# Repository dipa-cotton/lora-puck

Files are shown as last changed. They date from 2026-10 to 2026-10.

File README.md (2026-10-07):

# lora-puck
LoRA!!
## pictures
Screenshot 2026-10-07 at 12 41 12 AM
Screenshot 2026-10-07 at 12 42 32 AM
Screenshot 2026-10-07 at 12 42 04 AM
Screenshot 2026-10-07 at 12 41 37 AM

## project overview
A long range radio system with lots of features! it integrates boards with sensors and reads the data with an esp32, and communicates using an SX1262, on ham radio frequencies so i can pick them up from far far away :DD along with a 0.96 inch OLED display, a microSD card module, and more, this project is versatile and can do much more than your average tiny radio!
## pictures
There was no CAD Case built because this is going to be put in a solar powered plane built by an organization that I don't have the dimentions for yet. I will update the CAD as soon as I receive those dimentions!
### Overall Cost: $72
see BOM.csv for more specifics!

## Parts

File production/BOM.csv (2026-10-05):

Reference | Qty | Value | Cost | Link | Footprint | Datasheet
BT1 | 1 | Battery | 0.5 | https://www.aliexpress.us/item/3256807960114360.html?curPageLogUid=OKZYJvWZM2wn | Battery:BatteryHolder_Keystone_2462_2xAA
SW1,SW2 | 2 | SW_Push | Owned |  | Button_Switch_SMD:SW_Push_1P1T_NO_CK_PTS125Sx43SMTR
C1,C3,C4 | 3 | 100nf | 4 | https://www.aliexpress.com/ssr/300000512/BundleDeals2?productIds=1005006186888242%3A12000036220573161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 | Capacitor_SMD:C_0402_1005Metric_Pad0.74x0.62mm_HandSolder
C5 | 1 | 4.7 µF | included in kit |  | Capacitor_SMD:C_0402_1005Metric_Pad0.74x0.62mm_HandSolder
C6,C7 | 2 | 10 µF | included in kit |  | Capacitor_SMD:C_0402_1005Metric_Pad0.74x0.62mm_HandSolder
C12 | 1 | C_Polarized | Owned |  | Capacitor_THT:C_Radial_D6.3mm_H7.0mm_P2.50mm
J7 | 1 | Micro_SD_Card | 3.5 | https://www.mouser.com/en/ProductDetail/Wurth-Elektronik/693072010801?qs=7gQLVZk5cPmw4uU1mAcUFg%3D%3D | Connector_Card:microSD_HC_Wuerth_693072010801 | https://www.we-online.com/components/products/datasheet/693072010801.pdf
J3 | 1 | UV Sensor 240-370nm GUVA-S12SD 3528 | 3 | https://www.aliexpress.us/item/3256806094286151.html | Connector_PinHeader_2.54mm:PinHeader_1x03_P2.54mm_Vertical
J4 | 1 | AHT20+BMP280 Temperature Humidity Air Pressure | 3 | https://www.aliexpress.us/item/3256807516159141.html | Connector_PinHeader_2.54mm:PinHeader_1x04_P2.54mm_Vertical
J6 | 1 | GY-NEO6MV2 New NEO-6M GPS | 3 | https://www.aliexpress.us/item/3256807316352883.html | Connector_PinHeader_2.54mm:PinHeader_1x04_P2.54mm_Vertical
J8 | 1 | OLED | 3 | https://www.aliexpress.us/item/3256812792834091.html | Connector_PinHeader_2.54mm:PinHeader_1x04_P2.54mm_Vertical
J5 | 1 | 7700 Ambient Light Sensor | 3 | https://www.aliexpress.us/item/3256810505327028.html | Connector_PinHeader_2.54mm:PinHeader_1x05_P2.54mm_Vertical
J2 | 1 | ENS160+AHT21 | 3 | https://www.aliexpress.us/item/3256808312530292.html | Connector_PinHeader_2.54mm:PinHeader_1x08_P2.54mm_Vertical
J1 | 1 | USB_C_Receptacle_USB2.0_14P | 1 | https://www.digikey.com/en/products/detail/gct/USB4085-GF-A/9859662 | Connector_USB:USB_C_Receptacle_GCT_USB4085 | https://www.usb.org/sites/default/files/documents/usb_type-c.zip
Y1 | 1 | Crystal_GND24 | 0.5 | https://www.mouser.com/en/ProductDetail/Murata-Electronics/CSTLS16M0X55-B0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 | Crystal:Crystal_DS10_D1.0mm_L4.3mm_Horizontal_1EP_style1
FB1 | 1 | FerriteBead | 1.1 | https://www.digikey.com/en/products/detail/laird-signal-integrity-products/28C0236-0JW-10/806596 | Ferrite_THT:LairdTech_28C0236-0JW-10
U2 | 1 | SX1262IMLTRT | 9 | https://www.digikey.com/en/products/detail/semtech-corporation/SX1262IMLTRT/8564369 | Package_DFN_QFN:QFN-24-1EP_4x4mm_P0.5mm_EP2.6x2.6mm | https://semtech.file.force.com/sfc/dist/version/download/?oid=00DE0000000JelG&ids=0682R00000IjPWSQA3
U3 | 1 | AMS1117-3.3 | 0.5 | https://www.digikey.com/en/products/detail/umw/AMS1117-3-3/17635254 | Package_TO_SOT_SMD:SOT-223-3_TabPin2 | http://www.advanced-monolithic.com/pdf/ds1117.pdf
U4 | 1 | PE4259 | 1 | https://www.digikey.com/en/products/detail/psemi/4259-63/2614473 | Package_TO_SOT_SMD:SOT-363_SC-70-6 | https://lcsc.com/datasheet/lcsc_datasheet_2409301504_pSemi-PE4259-63_C470892.pdf
U5 | 1 | MCP1700x-330xxTO | 0.5 | https://www.digikey.com/en/products/detail/microchip-technology/MCP1700-3302E-TO/652680 | Package_TO_SOT_THT:TO-92_Inline | http://ww1.microchip.com/downloads/en/DeviceDoc/20001826D.pdf
L1 | 1 | 15µH | 1 | https://www.digikey.com/en/products/detail/bourns-inc/RL622-150K-RC/946867 | Resistor_SMD:R_0402_1005Metric_Pad0.72x0.64mm_HandSolder
L2 | 1 | 9.1nH | 0.5 | https://www.digikey.com/en/products/detail/murata-electronics/LQG15WZ9N1G02D/18679099?gclsrc=aw.ds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 | Resistor_SMD:R_0402_1005Metric_Pad0.72x0.64mm_HandSolder
R1,R2 | 2 | 5.1K | 4 | https://www.aliexpress.com/ssr/300000512/BundleDeals2?productIds=1005010764873718%3A12000053431302920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 | Resistor_SMD:R_0402_1005Metric_Pad0.72x0.64mm_HandSolder
R3,R4 | 2 | 10k | included in kit |  | Resistor_SMD:R_0402_1005Metric_Pad0.72x0.64mm_HandSolder
C2 | 1 | 1µF | included in kit |  | Resistor_SMD:R_0603_1608Metric
C8 | 1 | C | included in kit |  | Resistor_SMD:R_0603_1608Metric
C9 | 1 | 39pf | included in kit |  | Resistor_SMD:R_0603_1608Metric
C10,C11 | 2 | 3.3 pf | included in kit |  | Resistor_SMD:R_0603_1608Metric
C13 | 1 | 10µF | included in kit |  | Resistor_SMD:R_0603_1608Metric
C14 | 1 | 0.1µF | included in kit |  | Resistor_SMD:R_0603_1608Metric
R5 | 1 | 10D | included in kit |  | Resistor_SMD:R_0603_1608Metric
FL2 | 1 | 0900FM15K0039 | 0.5 | https://www.digikey.com/en/products/detail/johanson-technology-inc/0900FM15K0039001E/16639329 | RF_Converter:Balun_Johanson_0900FM15K0039 | https://www.johansontechnology.com/datasheets/0900FM15K0039/0900FM15K0039.pdf
U1 | 1 | ESP32-S3-WROOM-1 | 7 | https://www.digikey.com/en/products/detail/espressif-systems/ESP32-S3-WROOM-1-N8R8/15295891 | RF_Module:ESP32-S3-WROOM-1 | https://www.espressif.com/sites/default/files/documentation/esp32-s3-wroom-1_wroom-1u_datasheet_en.pdf
 |  |  | 52.1
 |  | shipping | 10 | 5 | 7
 |  | total | 74.1

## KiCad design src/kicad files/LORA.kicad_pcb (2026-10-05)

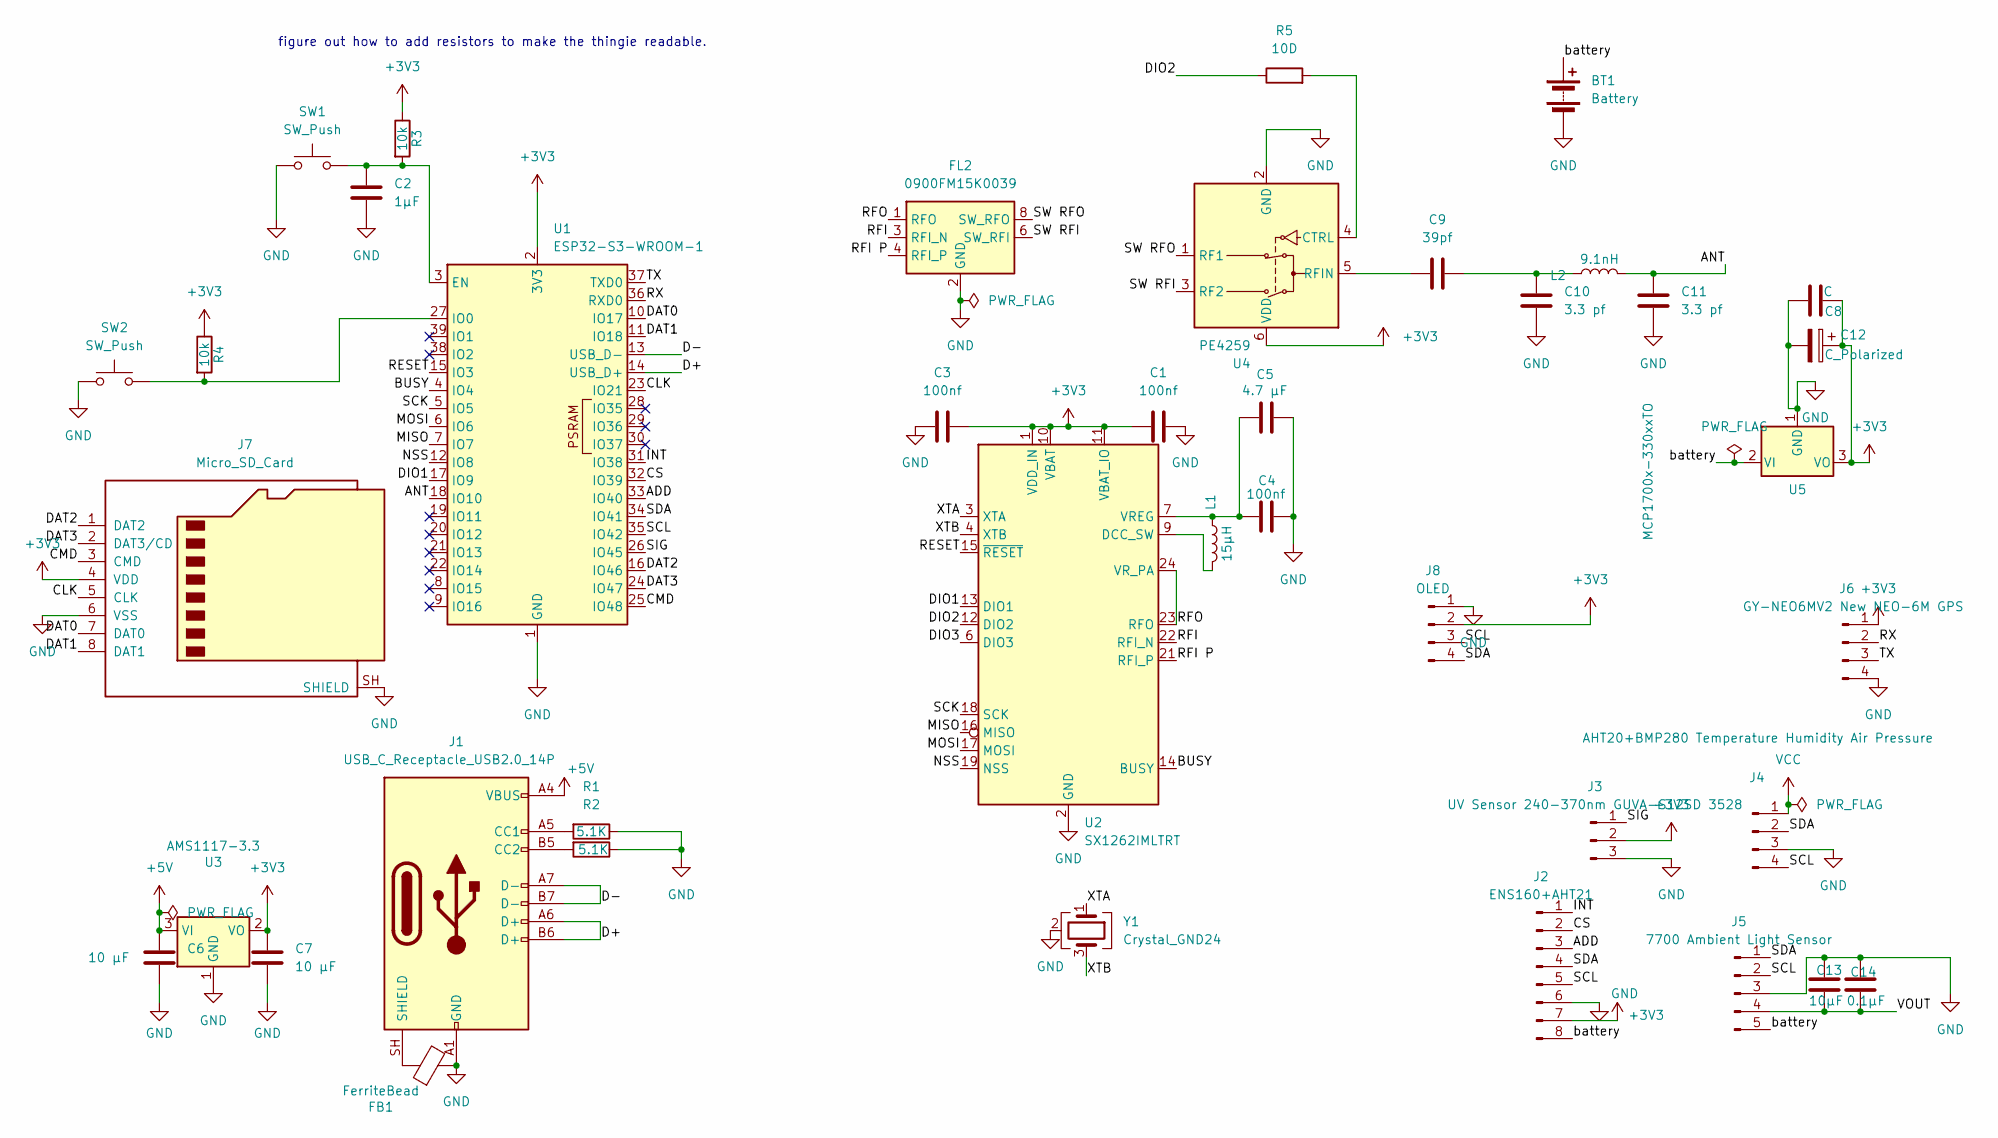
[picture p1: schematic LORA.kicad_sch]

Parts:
BT1: Battery; BatteryHolder_Keystone_2462_2xAA
C1, C3, C4: 100nf; C_0402_1005Metric_Pad0.74x0.62mm_HandSolder
C2: 1µF; R_0603_1608Metric
C5: 4.7 µF; C_0402_1005Metric_Pad0.74x0.62mm_HandSolder
C6, C7: 10 µF; C_0402_1005Metric_Pad0.74x0.62mm_HandSolder
C8: C; R_0603_1608Metric
C9: 39pf; R_0603_1608Metric
C10, C11: 3.3 pf; R_0603_1608Metric
C12: C_Polarized; C_Radial_D6.3mm_H7.0mm_P2.50mm
C13: 10µF; R_0603_1608Metric
C14: 0.1µF; R_0603_1608Metric
FB1: FerriteBead; LairdTech_28C0236-0JW-10
FL2: 0900FM15K0039; Balun_Johanson_0900FM15K0039
J1: USB_C_Receptacle_USB2.0_14P; USB_C_Receptacle_GCT_USB4085
J2: ENS160+AHT21; PinHeader_1x08_P2.54mm_Vertical
J3: UV Sensor 240-370nm GUVA-S12SD 3528; PinHeader_1x03_P2.54mm_Vertical
J4: AHT20+BMP280 Temperature Humidity Air Pressure; PinHeader_1x04_P2.54mm_Vertical
J5: 7700 Ambient Light Sensor; PinHeader_1x05_P2.54mm_Vertical
J6: GY-NEO6MV2 New NEO-6M GPS; PinHeader_1x04_P2.54mm_Vertical
J7: Micro_SD_Card; microSD_HC_Wuerth_693072010801
J8: OLED; PinHeader_1x04_P2.54mm_Vertical
L1: 15µH; R_0402_1005Metric_Pad0.72x0.64mm_HandSolder
L2: 9.1nH; R_0402_1005Metric_Pad0.72x0.64mm_HandSolder
R1, R2: 5.1K; R_0402_1005Metric_Pad0.72x0.64mm_HandSolder
R3, R4: 10k; R_0402_1005Metric_Pad0.72x0.64mm_HandSolder
R5: 10D; R_0603_1608Metric
SW1, SW2: SW_Push; SW_Push_1P1T_NO_CK_PTS125Sx43SMTR
U1: ESP32-S3-WROOM-1
U2: SX1262IMLTRT; QFN-24-1EP_4x4mm_P0.5mm_EP2.6x2.6mm
U3: AMS1117-3.3; SOT-223-3_TabPin2
U4: PE4259; SOT-363_SC-70-6
U5: MCP1700x-330xxTO; TO-92_Inline
Y1: Crystal_GND24; Crystal_DS10_D1.0mm_L4.3mm_Horizontal_1EP_style1

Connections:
+3V3: C1.1, C3.2, C7.1, C8.1, C12.1, J2.7, J3.2, J6.1, J7.4 (VDD), J8.2, R3.1, R4.1, U1.2 (3V3), U2.1 (VDD_IN), U2.10 (VBAT), U2.11 (VBAT_IO), U3.2 (VO), U4.6 (VDD), U5.3 (VO)
+5V: C6.1, J1.A4 (VBUS), J1.A9 (VBUS), J1.B4 (VBUS), J1.B9 (VBUS), U3.3 (VI)
/ADD: J2.3, U1.33 (IO40)
/ANT: C11.2, L2.2, U1.18 (IO10)
/BUSY: U1.4 (IO4), U2.14 (BUSY)
/CLK: J7.5 (CLK), U1.23 (IO21)
/CMD: J7.3 (CMD), U1.25 (IO48)
/CS: J2.2, U1.32 (IO39)
/D+: J1.A6 (D+), J1.B6 (D+), U1.14 (USB_D+)
/D-: J1.A7 (D-), J1.B7 (D-), U1.13 (USB_D-)
/DAT0: J7.7 (DAT0), U1.10 (IO17)
/DAT1: J7.8 (DAT1), U1.11 (IO18)
/DAT2: J7.1 (DAT2), U1.16 (IO46)
/DAT3: J7.2 (DAT3/CD), U1.24 (IO47)
/DIO1: U1.17 (IO9), U2.13 (DIO1)
/DIO2: R5.1, U2.12 (DIO2)
/DIO3: U2.6 (DIO3)
/INT: J2.1, U1.31 (IO38)
/MISO: U1.7 (IO7), U2.16 (MISO)
/MOSI: U1.6 (IO6), U2.17 (MOSI)
/NSS: U1.12 (IO8), U2.19 (NSS)
/RESET: U1.15 (IO3), U2.15 (~RESET)
/RFI: FL2.3 (RFI_N), U2.22 (RFI_N)
/RFI P: FL2.4 (RFI_P), U2.21 (RFI_P)
/RFO: FL2.1 (RFO), U2.23 (RFO), U2.24 (VR_PA)
/RX: J6.2, U1.36 (RXD0)
/SCK: U1.5 (IO5), U2.18 (SCK)
/SCL: J2.5, J4.4, J5.2, J8.3, U1.35 (IO42)
/SDA: J2.4, J4.2, J5.1, J8.4, U1.34 (IO41)
/SIG: J3.1, U1.26 (IO45)
/SW RFI: FL2.6 (SW_RFI), U4.3 (RF2)
/SW RFO: FL2.8 (SW_RFO), U4.1 (RF1)
/TX: J6.3, U1.37 (TXD0)
/VOUT: C13.2, C14.2, J5.4
/XTA: U2.3 (XTA), Y1.1
/XTB: U2.4 (XTB), Y1.3
/battery: BT1.1 (+), J2.8, J5.5, U5.2 (VI)
GND: BT1.2 (-), C1.2, C2.2, C3.1, C4.2, C5.2, C6.2, C7.2, C8.2, C10.1, C11.1, C12.2, C13.1, C14.1, FB1.2, FL2.2 (GND), FL2.5 (GND), FL2.7 (GND), FL2.9 (GND), FL2.10 (GND), J1.A1 (GND), J1.A12 (GND), J1.B1 (GND), J1.B12 (GND), J2.6, J3.3, J4.3, J5.3, J6.4, J7.6 (VSS), J7.SH (SHIELD), J8.1, R1.1, R2.1, SW1.1, SW2.1, U1.1 (GND), U1.40 (GND), U1.41 (GND), U2.2 (GND), U2.5 (GND), U2.8 (GND), U2.20 (GND), U2.25 (GND), U3.1 (GND), U4.2 (GND), U5.1 (GND), Y1.2 (G), Y1.4 (G)
unnamed: C9.1, C10.2, L2.1
unnamed: J1.A5 (CC1), R1.2
unnamed: J1.B5 (CC2), R2.2
unnamed: FB1.1, J1.SH (SHIELD)
unnamed: C2.1, R3.2, SW1.2, U1.3 (EN)
unnamed: R4.2, SW2.2, U1.27 (IO0)
unnamed: L1.2, U2.9 (DCC_SW)
unnamed: C4.1, C5.1, L1.1, U2.7 (VREG)
unnamed: R5.2, U4.4 (CTRL)
unnamed: C9.2, U4.5 (RFIN)
VCC: J4.1

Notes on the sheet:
figure out how to add resistors to make the thingie readable.

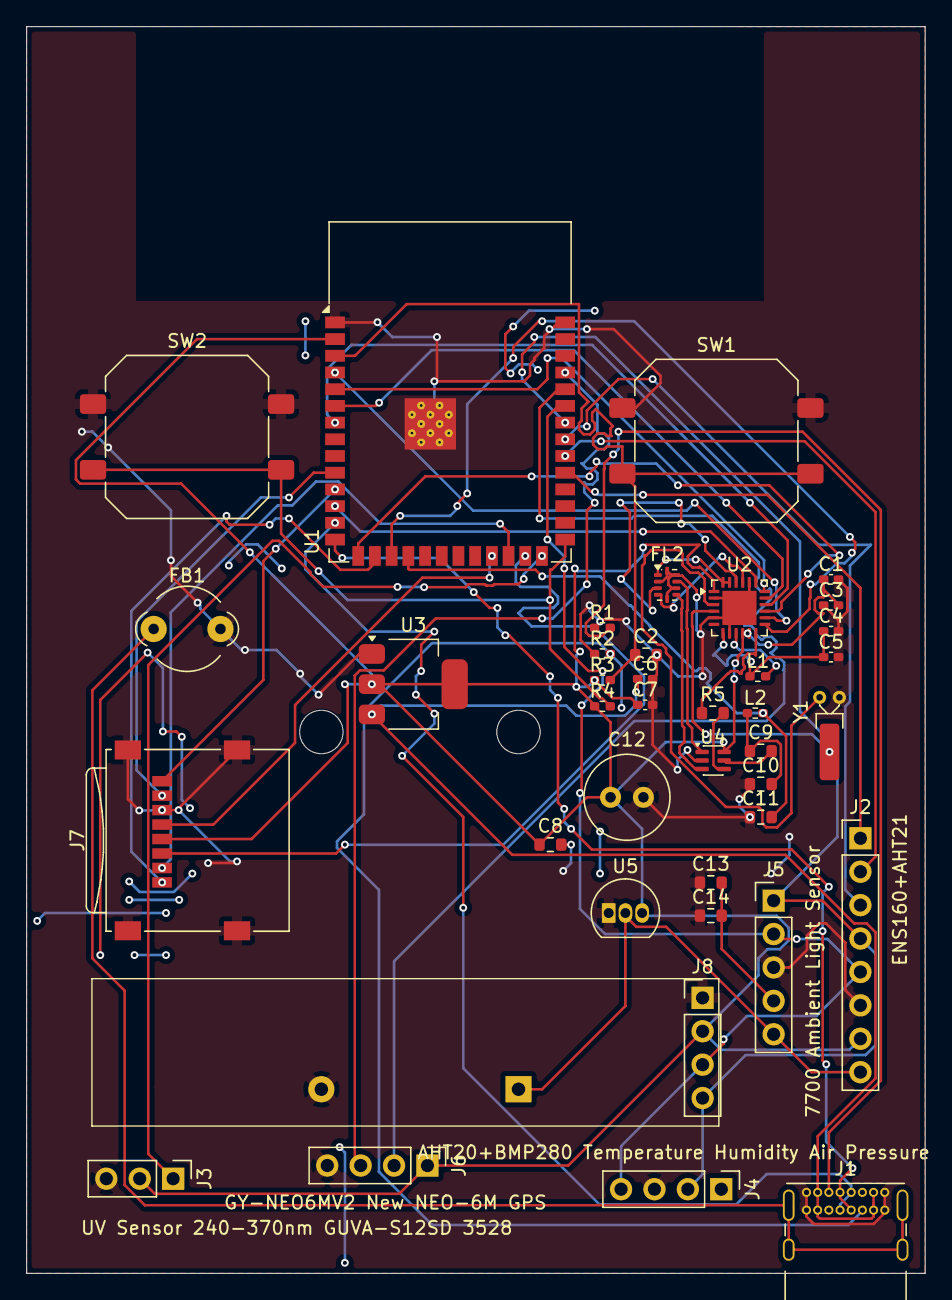
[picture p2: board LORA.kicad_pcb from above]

Board: 2 copper layers, 68.3 x 94.8 mm, 40 parts (1 on the bottom side), 47 nets.
